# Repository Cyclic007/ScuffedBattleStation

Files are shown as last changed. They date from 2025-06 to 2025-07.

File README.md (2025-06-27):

# ScuffedBattleStation

This is a custom cooling platorm/dock with a builtin USB-C hub and ethernet adapter. Built for Dell Inspireon 16.



















Green is fans and Gold is the PCB spot


# Total cost $119.45

| Part | cost | source |
|---|---|---|
| PCBA + components| $117.39 | JLCPCB |
| fans | $35.11 | https://www.digikey.com/en/products/detail/same-sky-formerly-cui-devices/CFM-8025V-232-330/7620559 |

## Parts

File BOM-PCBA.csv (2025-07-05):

JLCPCB BOM Tool - BOM Matching
BOM name:BOM-main-JLCPCB Assembly Order.xlsx |  |  |  | Download Time:2025-06-21 21:39:04 |  |  |  | * Our matching results are updated in real-time, but stock and prices may change. If it's been over 24 hours, please re-match before placing your order.
PCB Assembled Qty:5 |  |  |  | Est. Total Price:51.5611
Your BOM | Order Information |  |  |  |  | Matched Parts |  |  |  |  |  |  | Order Information
Top Designator | JLCPCB Part # | Bottom Designator | Comment | Footprint | JLCPCB Part # | Matches | Part # | Manufacturer | Footprint | Description | Category | Warning | JLCPCB Part # | Product link | Lib Type | Qty | Source | Total Price ($)
C1,C3,C6 | C124760 |  | 0.1pF | C_0201_0603Metric |  | Select by System | C0201C0G1R0B500NTA | EYANG(Shenzhen Eyang Tech Development) | 201 | 50V 1pF C0G ±0.1pF 0201 Multilayer Ceramic Capacitors MLCC - SMD/SMT ROHS | Multilayer Ceramic Capacitors MLCC - SMD/SMT |  | C124760 | https://jlcpcb.com/partdetail/126037-C0201C0G1R0B500NTA/C124760 | Extended | 20 | 20 JLCPCB | 0.042
C2 | C56903 |  | 33pF | C_0201_0603Metric |  | Select by System | 0201CG330J500NT | FH (Guangdong Fenghua Advanced Tech) | 201 | 50V 33pF C0G ±5% 0201 Multilayer Ceramic Capacitors MLCC - SMD/SMT ROHS | Multilayer Ceramic Capacitors MLCC - SMD/SMT |  | C56903 | https://jlcpcb.com/partdetail/57933-0201CG330J500NT/C56903 | Extended | 20 | 20 JLCPCB | 0.014
C10,C4,C5,C8,C9 | C181047 |  | 0.1 | C_0201_0603Metric |  | Select by System | GRM033C81E104KE14D | Murata Electronics | 201 | 0.1 µF ±10% 25V Ceramic Capacitor X6S 0201 (0603 Metric) | Global Sourcing Parts |  | C181047 | https://jlcpcb.com/partdetail/192444-GRM033C81E104KE14D/C181047 | Extended | 20 | 20 JLCPCB | 0.172
C11 | C335103 |  | 4.7 | C_0201_0603Metric |  | Select by System | GRM035R60J475ME15D | Murata Electronics | 201 | 6.3V 4.7uF X5R ±20% 0201 Multilayer Ceramic Capacitors MLCC - SMD/SMT ROHS | Multilayer Ceramic Capacitors MLCC - SMD/SMT |  | C335103 | https://jlcpcb.com/partdetail/313624-GRM035R60J475ME15D/C335103 | Extended | 7 | 7 JLCPCB | 0.2562
FB1 | C442498 |  | FerriteBead | L_Ferrocore_DLG-0302 |  | Select by System | ILHB0805ER121V | Vishay Intertech | 805 | 120 Ohms @ 100 MHz 1 Ferrite Bead 0805 (2012 Metric) 5A 30mOhm | Global Sourcing Parts |  | C442498 | https://jlcpcb.com/partdetail/VishayIntertech-ILHB0805ER121V/C442498 | Extended | 6 | 6 JLCPCB | 0.3792
J1,J3,J4 | C3197788 |  | 1003-031-01220-TR | USB_C_Receptacle_Amphenol_12401548E4-2A_CircularHoles |  | Select by Customer | 12401826E412A | Amphenol ICC | SMD | SMD USB Connectors ROHS | USB Connectors |  | C3197788 | https://jlcpcb.com/partdetail/AmphenolICC-12401826E412A/C3197788 | Extended | 6 | 6 JLCPCB | 8.046
J6 | C7077933 |  | RJ45_Amphenol_RJMG1BD3B8K1ANR | RJ45_Amphenol_RJMG1BD3B8K1ANR |  | Select by Customer | ARJM11C7-009-AB-EW2 | Abracon LLC | ?? | 1 Shielded Gold WithLED -40?~+85? Plugin Ethernet Connectors / Modular Connectors (RJ45 RJ11) ROHS | Ethernet Connectors / Modular Connectors (RJ45 RJ11) |  | C7077933 | https://jlcpcb.com/partdetail/AbraconLLC-ARJM11C7_009_ABEW2/C7077933 | Extended | 2 | 2 JLCPCB | 10.71
R1,R2,R3,R4,R6,R7 | C100142 |  | 5.1k | R_0201_0603Metric |  | Select by System | CR0201FH5101G | LIZ Elec | 201 | 50mW Thick Film Resistors 25V ±1% ±250ppm/? 5.1k? 0201 Chip Resistor - Surface Mount ROHS | Chip Resistor - Surface Mount |  | C100142 | https://jlcpcb.com/partdetail/LIZElec-CR0201FH5101G/C100142 | Extended | 22 | 22 JLCPCB | 0.0154
R5 | C138116 |  | 12.0k | R_0201_0603Metric |  | Select by System | RC0201JR-0712KL | YAGEO | 201 | 50mW Thick Film Resistors 25V ±5% ±200ppm/? 12k? 0201 Chip Resistor - Surface Mount ROHS | Chip Resistor - Surface Mount |  | C138116 | https://jlcpcb.com/partdetail/YAGEO-RC0201JR0712KL/C138116 | Extended | 20 | 20 JLCPCB | 0.008
R8 | C226459 |  | 1.0M | R_0201_0603Metric |  | Select by Customer | AC0201FR-071ML | YAGEO | 201 | 50mW Thick Film Resistors 25V ±1% ±200ppm/? 1M? 0201 Chip Resistor - Surface Mount ROHS | Chip Resistor - Surface Mount |  | C226459 | https://jlcpcb.com/partdetail/YAGEO-AC0201FR071ML/C226459 | Extended | 20 | 20 JLCPCB | 0.032
R9 | C239755 |  | 12.4k | R_0201_0603Metric |  | Select by System | RM02FTN1242 | TA-I Tech | 201 | 50mW Thick Film Resistors 25V ±1% ±200ppm/? 12.4k? 0201 Chip Resistor - Surface Mount ROHS | Chip Resistor - Surface Mount |  | C239755 | https://jlcpcb.com/partdetail/TA_ITech-RM02FTN1242/C239755 | Extended | 20 | 20 JLCPCB | 0.042
R10,R11,R12,R13,R14 | C100148 |  | 10 | R_0201_0603Metric |  | Select by System | CR0201JH0100G | LIZ Elec | 201 | 50mW Thick Film Resistors 25V ±5% ±600ppm/? 10? 0201 Chip Resistor - Surface Mount ROHS | Chip Resistor - Surface Mount |  | C100148 | https://jlcpcb.com/partdetail/LIZElec-CR0201JH0100G/C100148 | Extended | 20 | 20 JLCPCB | 0.016
R15,R16 | C100175 |  | 330 | R_0201_0603Metric |  | Select by System | CR0201JH0331G | LIZ Elec | 201 | ±5% 330? 0201 Chip Resistor - Surface Mount ROHS | Chip Resistor - Surface Mount |  | C100175 | https://jlcpcb.com/partdetail/LIZElec-CR0201JH0331G/C100175 | Extended | 20 | 20 JLCPCB | 0.016
R17 | C158556 |  | 39.2K | R_0201_0603Metric |  | Select by System | RTT013922FTH | RALEC | 201 | 50mW Thick Film Resistors 25V ±1% ±200ppm/? 39.2k? 0201 Chip Resistor - Surface Mount ROHS | Chip Resistor - Surface Mount |  | C158556 | https://jlcpcb.com/partdetail/RALEC-RTT013922FTH/C158556 | Extended | 20 | 20 JLCPCB | 0.018
R18 | C320985 |  | 61.9K | R_0201_0603Metric |  | Select by System | RC-01W6192FT | FH (Guangdong Fenghua Advanced Tech) | 201 | 50mW Thick Film Resistors 25V ±1% ±200ppm/? 61.9k? 0201 Chip Resistor - Surface Mount ROHS | Chip Resistor - Surface Mount |  | C320985 | https://jlcpcb.com/partdetail/301890-RC01W6192FT/C320985 | Extended | 7 | 7 JLCPCB | 0.0063
U2 | C633505 |  | LAN9512i | QFN-64-1EP_9x9mm_P0.5mm_EP7.3x7.3mm |  | Select by System | LAN9512I-JZX | Microchip Tech | QFN-64-EP(9x9) | QFN-64-EP(9x9) Ethernet Controllers ROHS | Ethernet Controllers |  | C633505 | https://jlcpcb.com/partdetail/MicrochipTech-LAN9512IJZX/C633505 | Extended | 2 | 2 JLCPCB | 30.81
Y2 | C2901600 |  | KC2520Z | Oscillator_SMD_Kyocera_KC2520Z-4Pin_2.5x2.0mm |  | Select by Customer | SX2M24.000M20F30TNN | Shenzhen SCTF Elec | SMD2520-4P | 1.62V~3.63V ±20ppm 10mA ±30ppm CMOS 24MHz SMD2520-4P Crystal Oscillators ROHS | Crystal Oscillators |  | C2901600 | https://jlcpcb.com/partdetail/3151413-SX2M24000M20F30TNN/C2901600 | Extended | 2 | 2 JLCPCB | 0.978

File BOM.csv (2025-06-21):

Part | cost | source
PCBA + components | $117.39 | JLCPCB
fans | $26.56 | https://www.digikey.com/en/products/detail/nidec-components-corporation/F310R-05LC/1165517

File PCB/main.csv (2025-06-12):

Id | Designator | Footprint | Quantity | Designation | Supplier and ref
1 | J1,J3,J4 | USB_C_Receptacle_Amphenol_12401548E4-2A_CircularHoles | 3 | USB_C_Receptacle
2 | R2,R7,R4,R1,R5,R3 | R_0815_2038Metric | 6 | R
3 | M4,M1,M2,M3 | FanPinHeader_1x03_P2.54mm_Vertical | 4 | Fan_PC_Chassis
4 | J2 | RJ45_Amphenol_54602-x08_Horizontal | 1 | RJ45
5 | U2 | QFN-64-1EP_9x9mm_P0.5mm_EP7.3x7.3mm | 1 | LAN9512i
6 | SW1 | SW_CK_JS202011CQN_DPDT_Straight | 1 | SW_DPDT_x2

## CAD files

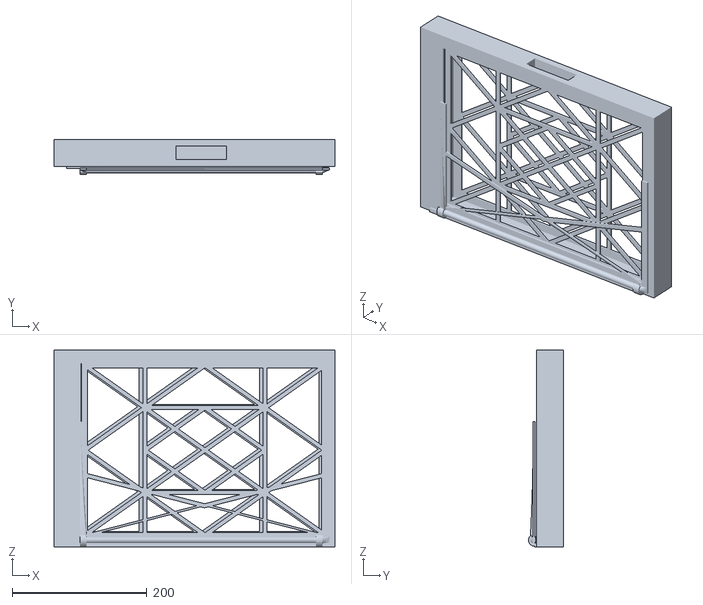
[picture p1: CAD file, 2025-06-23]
Case/Full v3.stl
416.8 x 52.0 x 291.9

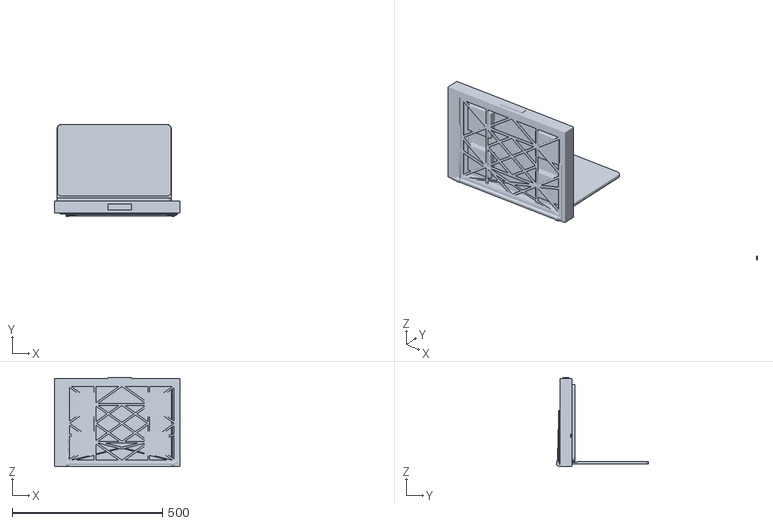
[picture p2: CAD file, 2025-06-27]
Full v6.stl
1073.3 x 307.0 x 295.9

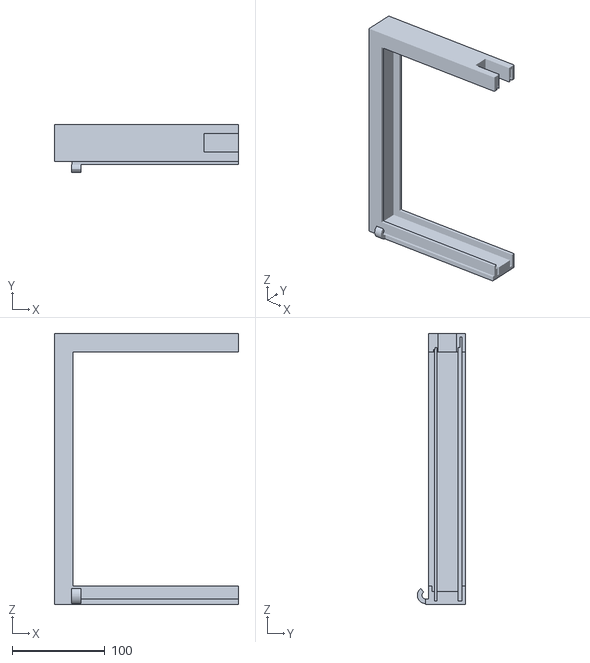
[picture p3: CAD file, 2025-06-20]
Case/frame v12.stl
198.4 x 52.0 x 291.9

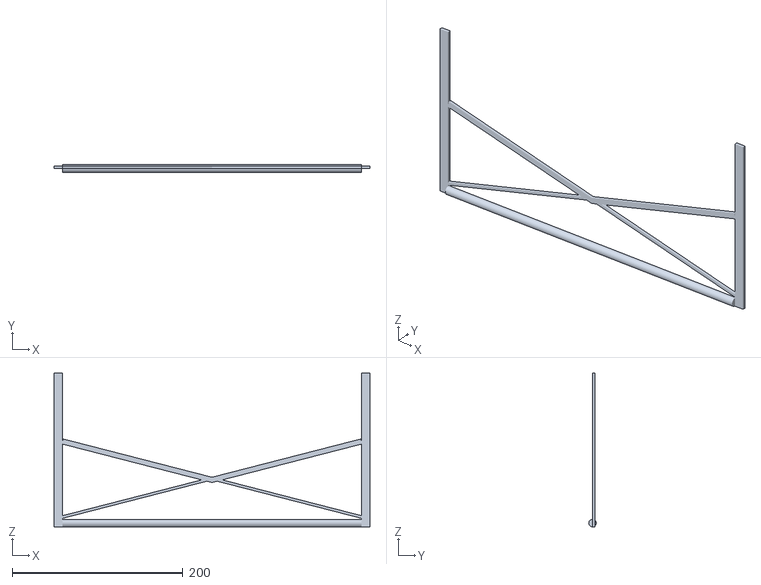
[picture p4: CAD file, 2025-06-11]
Case/feet v1.stl
370.0 x 8.85 x 180.0

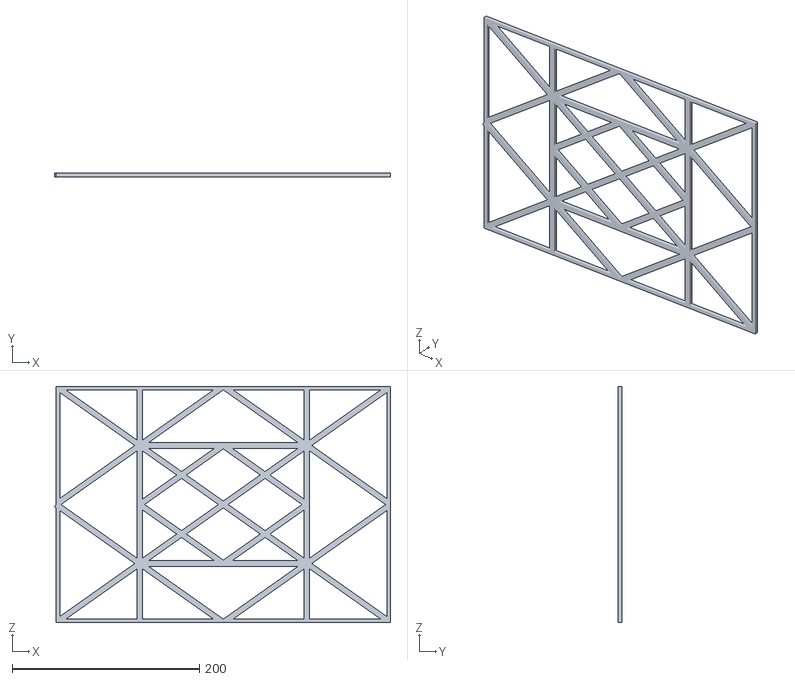
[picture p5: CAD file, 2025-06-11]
Case/platform v1.stl
358.5 x 4.00 x 251.9

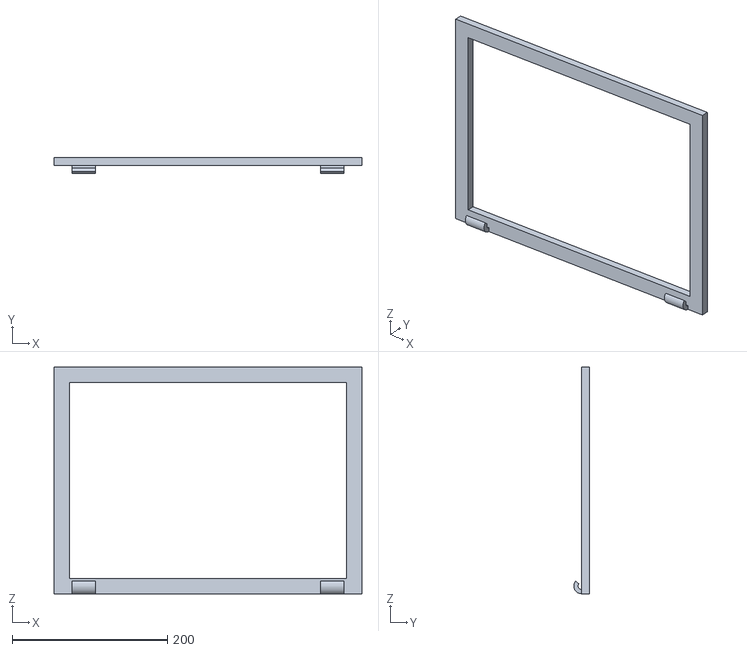
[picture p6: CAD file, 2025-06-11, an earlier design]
Case/frame v3.stl
396.8 x 20.0 x 291.9

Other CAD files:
Case/feet v2.f3d
Case/frame v12.f3d
Case/platform v3.f3d

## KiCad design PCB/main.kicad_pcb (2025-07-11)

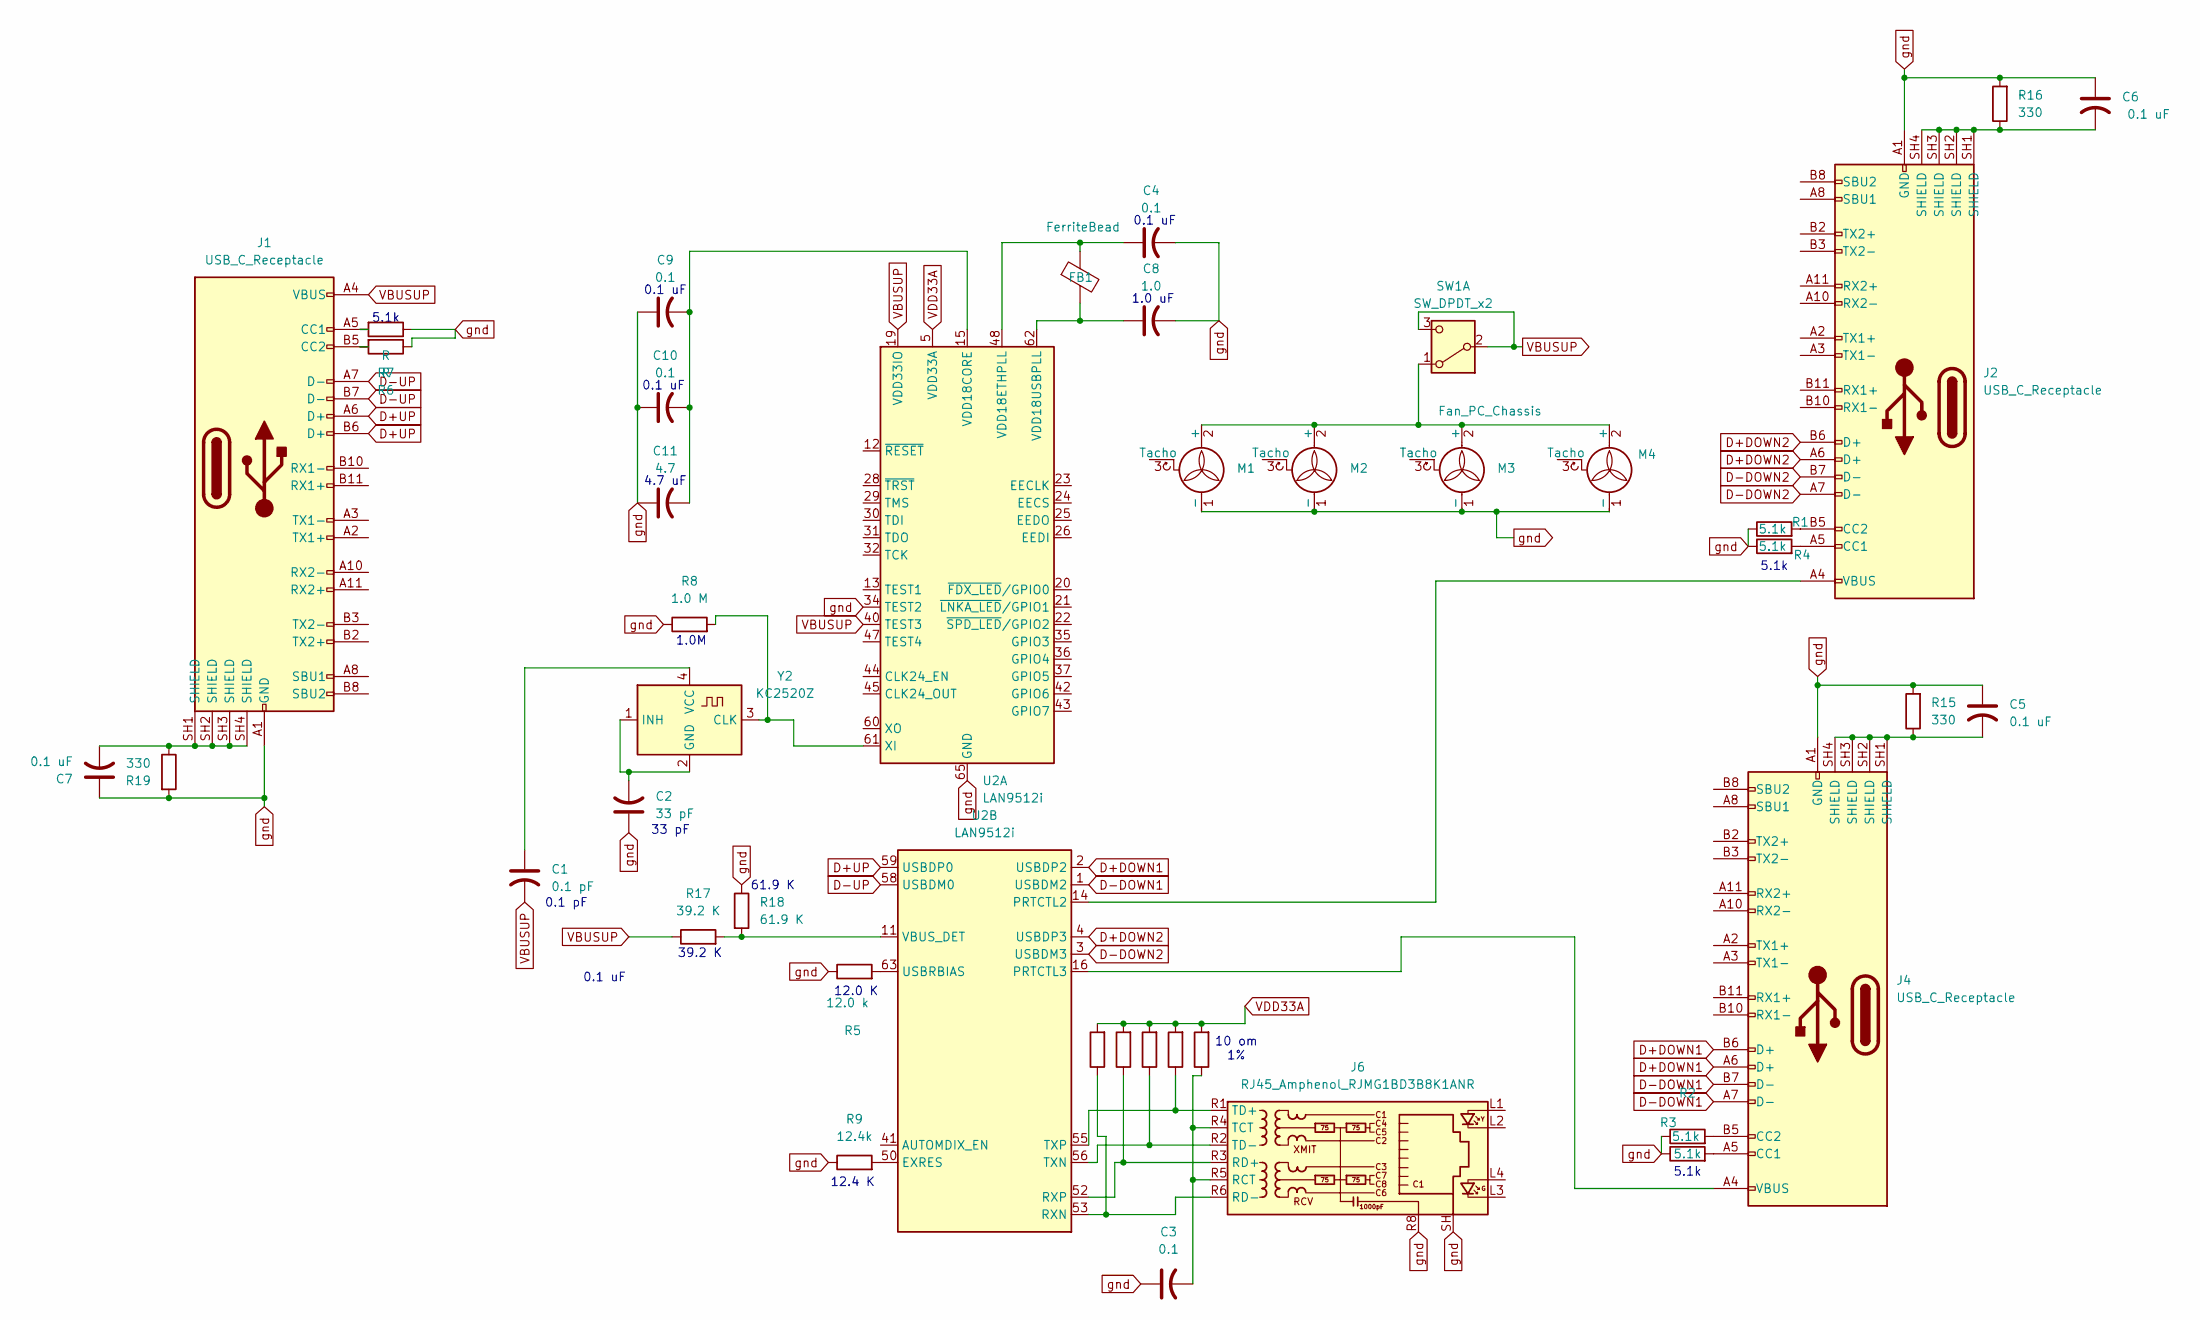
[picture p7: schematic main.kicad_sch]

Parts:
C1: 0.1 pF; C_0201_0603Metric
C2: 33 pF; C_0201_0603Metric
C3, C4, C9, C10: 0.1; C_0201_0603Metric
C5, C7: 0.1 uF; C_0201_0603Metric
C6: 330; C_0201_0603Metric
C8: 1.0; C_0201_0603Metric
C11: 4.7; C_0201_0603Metric
FB1: FerriteBead; L_Ferrocore_DLG-0302
J1, J2, J4: USB_C_Receptacle; AMPHENOL_12401826E412A
J6: RJ45_Amphenol_RJMG1BD3B8K1ANR
M1, M2, M3, M4: Fan_PC_Chassis; FanPinHeader_1x03_P2.54mm_Vertical
R1, R2, R3, R4: 5.1k; R_0201_0603Metric
R5: 12.0 k; R_0201_0603Metric
R6, R7: R; R_0201_0603Metric
R8: 1.0 M; R_0201_0603Metric
R9: 12.4k; R_0201_0603Metric
R10, R11, R12, R13, R14: 10; R_0201_0603Metric
R15, R19: 330; R_0201_0603Metric
R16: 0.1 uF; R_0201_0603Metric
R17: 39.2 K; R_0201_0603Metric
R18: 61.9 K; R_0201_0603Metric
SW1: SW_DPDT_x2; SW_CK_JS202011CQN_DPDT_Straight
U2: LAN9512i; QFN-64-1EP_9x9mm_P0.5mm_EP7.3x7.3mm
Y2: KC2520Z; Oscillator_SMD_Kyocera_KC2520Z-4Pin_2.5x2.0mm

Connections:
D+DOWN1: J4.A6 (D+), J4.B6 (D+), U2.2 (USBDP2)
D+DOWN2: J2.A6 (D+), J2.B6 (D+), U2.4 (USBDP3)
D+UP: J1.A6 (D+), J1.B6 (D+), U2.59 (USBDP0)
D-DOWN1: J4.A7 (D-), J4.B7 (D-), U2.1 (USBDM2)
D-DOWN2: J2.A7 (D-), J2.B7 (D-), U2.3 (USBDM3)
D-UP: J1.A7 (D-), J1.B7 (D-), U2.58 (USBDM0)
unnamed: C5.2, J4.SH1 (SHIELD), J4.SH2 (SHIELD), J4.SH3 (SHIELD), J4.SH4 (SHIELD), R15.1
unnamed: C6.2, J2.SH1 (SHIELD), J2.SH2 (SHIELD), J2.SH3 (SHIELD), J2.SH4 (SHIELD), R16.1
unnamed: C7.2, J1.SH1 (SHIELD), J1.SH2 (SHIELD), J1.SH3 (SHIELD), J1.SH4 (SHIELD), R19.1
unnamed: C9.2, C10.2, C11.2, U2.15 (VDD18CORE), U2.38 (VDD18CORE)
unnamed: J1.A5 (CC1), R7.2
unnamed: J1.B5 (CC2), R6.2
unnamed: J2.A5 (CC1), R4.2
unnamed: J2.B5 (CC2), R1.2
unnamed: J4.A5 (CC1), R3.2
unnamed: J4.B5 (CC2), R2.2
unnamed: C3.2, J6.R4 (TCT), J6.R5 (RCT), R14.1
unnamed: J6.R3 (RD+), R11.1, U2.52 (RXP)
unnamed: J6.R6 (RD-), R10.1, U2.53 (RXN)
unnamed: J6.R1 (TD+), R13.1, U2.55 (TXP)
unnamed: J6.R2 (TD-), R12.1, U2.56 (TXN)
unnamed: M1.2 (+), M2.2 (+), M3.2 (+), M4.2 (+), SW1.1 (A)
unnamed: C4.1, FB1.1, U2.48 (VDD18ETHPLL)
unnamed: C8.1, FB1.2, U2.62 (VDD18USBPLL)
unnamed: R8.2, U2.61 (XI), Y2.3 (CLK)
unnamed: R9.2, U2.50 (EXRES)
unnamed: J2.A4 (VBUS), J2.A9 (VBUS), J2.B4 (VBUS), J2.B9 (VBUS), U2.14 (PRTCTL2)
unnamed: J4.A4 (VBUS), J4.A9 (VBUS), J4.B4 (VBUS), J4.B9 (VBUS), U2.16 (PRTCTL3)
unnamed: R5.2, U2.63 (USBRBIAS)
unnamed: R17.2, R18.2, U2.11 (VBUS_DET)
unnamed: C2.2, Y2.1 (INH), Y2.2 (GND)
unnamed: C1.1, Y2.4 (VCC)
VBUSUP: C1.2, J1.A4 (VBUS), J1.A9 (VBUS), J1.B4 (VBUS), J1.B9 (VBUS), R17.1, SW1.2 (B), SW1.3 (C), U2.19 (VDD33IO), U2.27 (VDD33IO), U2.33 (VDD33IO), U2.39 (VDD33IO), U2.40 (TEST3), U2.46 (VDD33IO)
VDD33A: R10.2, R11.2, R12.2, R13.2, R14.2, U2.5 (VDD33A), U2.10 (VDD33A), U2.49 (VDD33A), U2.51 (VDD33A), U2.54 (VDD33A), U2.57 (VDD33A), U2.64 (VDD33A)
gnd: C2.1, C3.1, C4.2, C5.1, C6.1, C7.1, C8.2, C9.1, C10.1, C11.1, J1.A1 (GND), J1.A12 (GND), J1.B1 (GND), J1.B12 (GND), J2.A1 (GND), J2.A12 (GND), J2.B1 (GND), J2.B12 (GND), J4.A1 (GND), J4.A12 (GND), J4.B1 (GND), J4.B12 (GND), J6.R8, J6.SH, M1.1 (-), M2.1 (-), M3.1 (-), M4.1 (-), R1.1, R2.1, R3.1, R4.1, R5.1, R6.1, R7.1, R8.1, R9.1, R15.2, R16.2, R18.1, R19.2, U2.34 (TEST2), U2.65 (GND)

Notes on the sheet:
0.1 uF
61.9 K
33 pF
5.1k
0.1 pF
10 om 1%
12.4 K
39.2 K
4.7 uF
12.0 K
1.0 uF
1.0M

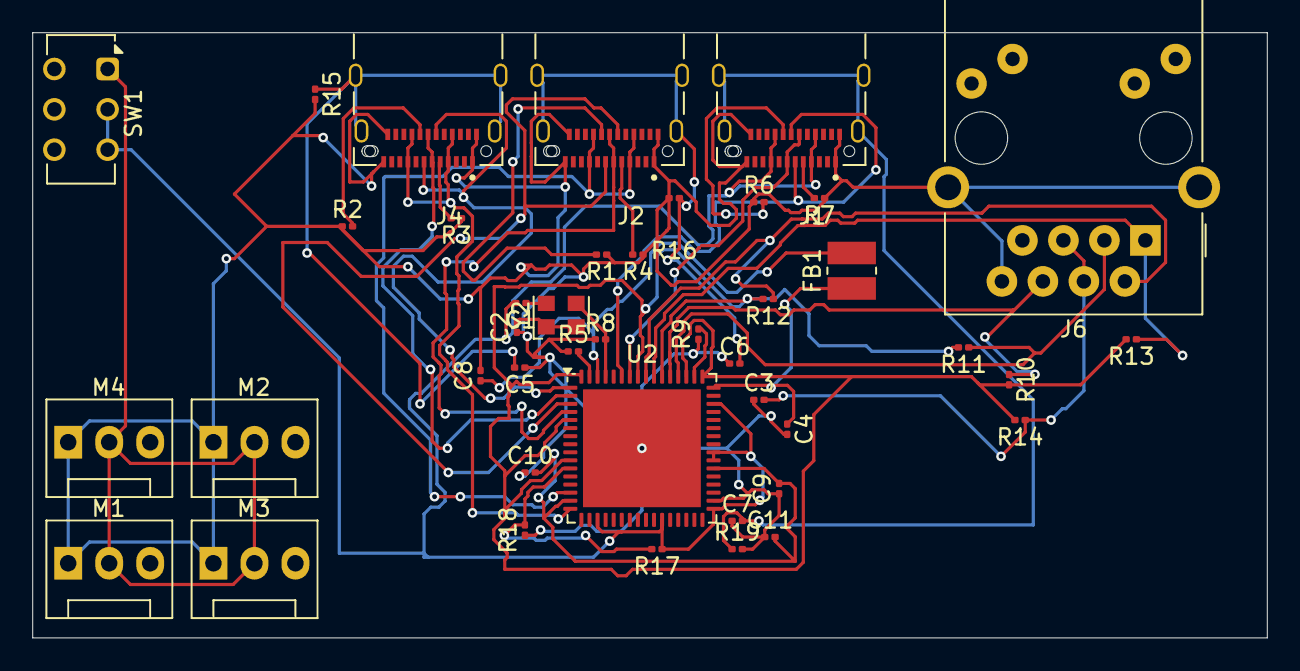
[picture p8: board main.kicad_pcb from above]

Board: 2 copper layers, 76.5 x 37.5 mm, 42 parts (0 on the bottom side), 35 nets.

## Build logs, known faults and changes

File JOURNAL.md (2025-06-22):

---
title: "ScuffedBattleStation"
author: "Cyclic"
description: "A colling stand and cool thing for my laptop"
created_at: "2025-6-05"
---

#### June 7 actualy starting

so the plan is to have a cooling pad that includes 2 usb-c ports(from a hub) and an ethernet port

The Specs

- https://en.wikipedia.org/wiki/IEEE_802.3
- https://en.wikipedia.org/wiki/USB-C

so I start on the scematic

I am goning to use LAN9513i

- http://ww1.microchip.com/downloads/en/DeviceDoc/00002305A.pdf

I also am going to be useing USB 2.0

spent about 1hr trying to find the right risitor

** Total Time spent 5hr ** 

#### June 7 part 2

I finished the scematic and PCB 





I am going to use normal fan connectors for my thing

I am also going to need to use PCBway's assembely thing because I can't hand solder a good handful of the components

** Total time spent 1hr 

#### June 9 fixing PCB 

My PCB has a problem where my drill holes are too small and need fixing



Finished PCB.

** Total Time Spent 1hr **

#### June 11 making 3d models







** Total time spent 3 hr **

#### June 12 working more on 3d models







in this rendition there are now slots in the frame to put the platforms and made it actually possible to put the feet on the frame

While I was trying to find price I found that JLPCB does not have the exact parts I need so I am going to have them find the right parts 

JLCPCB also has no USBC receptacles so I am going to get them separately and hand solder

I am also going to hand solder the fans directly to the PCB 

Also prepped to ship

** Total time spent 5 hr **

#### June 14 PCB fixing

I found out that I screwed up the pcb and had all of my USB-c connectors flipped in the wrong direction so I fixed that and rerouted

I also found that I forgot to attach a resistor and forgot to connect shield to gnd



** Total time spent 1 hr ** 

#### June 16 adding crystals

I found that the controller I am useing needs an external crystal ossolator and needs all of the 3.3v pins connected so I fixed that and added KC2520Z1.84320C1KX00 to the PCB

I also fixed BOM

I also fixed the PCB and got an actual price for the PCBA





** Total time spent 2hr **

#### June 20/21 Fixing things at the pool

I found that there are more things that are wrong in my design and I need to read more datasheets and docs to fix it and also need to redo all the wireing 





I also got the new price 

I will ask for rereview.

** total time spent 4hr **

#### June 22 Almost there

got told that my caps are too far from the MCU so I moved them and fixed that



** Total time spent 30 min **

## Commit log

2025-06-07 doin stuff
    [main.kicad_pcb, main.kicad_sch]
2025-06-11 making cool stuff
    [feet v1.stl, frame v3.stl, platform v1.stl]
2025-06-12 getting stuff done
    [BOM-main.csv, feet v2.f3d, frame v12.f3d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]
2025-06-12 adding stuff
    [main.kicad_pcb]
2025-06-12 adding BOM
    [BOM.csv]
2025-06-14 fixing PCB
    [main.kicad_pcb, main.kicad_sch]
2025-06-20 fixing things
    [BOM-main.csv, frame v12.stl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]
2025-06-21 fixing lots of things
    [BOM-PCBA.csv, BOM-main.csv, BOM.csv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]
2025-06-22 fixing caps
    [main.kicad_pcb]
2025-06-23 added full assembley
    [Full v3.stl]
2025-07-08 fixing footprints
    [main.kicad_pcb, main.kicad_sch]
2025-07-11 happy times
    [BOM-main.csv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]
